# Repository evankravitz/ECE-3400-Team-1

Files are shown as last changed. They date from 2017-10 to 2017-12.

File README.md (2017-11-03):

# [Start Bootstrap - Agency](https://startbootstrap.com/template-overviews/agency/)

[Agency](https://startbootstrap.com/template-overviews/agency/) is a one page agency portfolio theme for [Bootstrap](http://getbootstrap.com/) created by [Start Bootstrap](http://startbootstrap.com/). This theme features several content sections, a responsive portfolio grid with hover effects, full page portfolio item modals, a responsive timeline, and a working PHP contact form.

## Preview

Agency Preview (https://blackrockdigital.github.io/startbootstrap-agency/)

**[View Live Preview](https://blackrockdigital.github.io/startbootstrap-agency/)**

## Status




dependencies Status (https://david-dm.org/BlackrockDigital/startbootstrap-agency)
devDependencies Status (https://david-dm.org/BlackrockDigital/startbootstrap-agency?type=dev)

## Download and Installation

To begin using this template, choose one of the following options to get started:
* [Download the latest release on Start Bootstrap](https://startbootstrap.com/template-overviews/agency/)
* Install via npm: `npm i startbootstrap-agency`
* Clone the repo: `git clone https://github.com/BlackrockDigital/startbootstrap-agency.git`
* [Fork, Clone, or Download on GitHub](https://github.com/BlackrockDigital/startbootstrap-agency)

## Usage

### Basic Usage

After downloading, simply edit the HTML and CSS files included with the template in your favorite text editor to make changes. These are the only files you need to worry about, you can ignore everything else! To preview the changes you make to the code, you can open the `index.html` file in your web browser.

### Advanced Usage

After installation, run `npm install` and then run `gulp dev` which will open up a preview of the template in your default browser, watch for changes to core template files, and live reload the browser when changes are saved. You can view the `gulpfile.js` to see which tasks are included with the dev environment.

#### Gulp Tasks

- `gulp` the default task that builds everything
- `gulp dev` browserSync opens the project in your default browser and live reloads when changes are made
- `gulp sass` compiles SCSS files into CSS
- `gulp minify-css` minifies the compiled CSS file
- `gulp minify-js` minifies the themes JS file
- `gulp copy` copies dependencies from node_modules to the vendor directory

## Bugs and Issues

Have a bug or an issue with this template? [Open a new issue](https://github.com/BlackrockDigital/startbootstrap-agency/issues) here on GitHub or leave a comment on the [template overview page at Start Bootstrap](http://startbootstrap.com/template-overviews/agency/).

## Custom Builds

You can hire Start Bootstrap to create a custom build of any template, or create something from scratch using Bootstrap. For more information, visit the **[custom design services page](https://startbootstrap.com/bootstrap-design-services/)**.

## About

Start Bootstrap is an open source library of free Bootstrap templates and themes. All of the free templates and themes on Start Bootstrap are released under the MIT license, which means you can use them for any purpose, even for commercial projects.

* https://startbootstrap.com
* https://twitter.com/SBootstrap

Start Bootstrap was created by and is maintained by **[David Miller](http://davidmiller.io/)**, Owner of [Blackrock Digital](http://blackrockdigital.io/).

* http://davidmiller.io
* https://twitter.com/davidmillerskt
* https://github.com/davidtmiller

Start Bootstrap is based on the [Bootstrap](http://getbootstrap.com/) framework created by [Mark Otto](https://twitter.com/mdo) and [Jacob Thorton](https://twitter.com/fat).

## Copyright and License

Copyright 2013-2017 Blackrock Digital LLC. Code released under the [MIT](https://github.com/BlackrockDigital/startbootstrap-agency/blob/gh-pages/LICENSE) license.

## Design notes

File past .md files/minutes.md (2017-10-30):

# Minutes

### 9/1 Meeting

11:15 Upson 349

Present: All

Absent: None

Meeting begins with pleasantries and small talk.
Evan discusses adding everyone to Github.
Turns out issue is with Cornell’s github enterprises system.
Evan adds everyone’s personal accounts..
Everyone sends Evan headshots to add to the website.
Begin writing the contract.
Various discussions about elements of the contract, etc (see contract for more details).
Contract signed.
We talk about adding more pages to the website..
Michael will add robot stuff to the lab1 page.
How to submit? Email to kirsten?
MEETING ADJOURNED at 12:06PM

### 9/15 Meeting:
11:15 Kimball B11

Present: All
Absent: Radhika, due to illness.  We hope she feels better soon :( 

We discuss the work we have done on our individual subteams and deliberate on how to tackle the rest of the objectives related to lab 2 and milestone 1. 
Optical team realizes they have not made the modifications necessary to make the Arduino light an LED in response to incident IR light, so we discuss when we can meet to work on that objective.
The robotics team explains that our robot is able to stop at junctions with extreme accuracy, but it is having trouble following a line.  We figure the reason the robot is having this trouble is because the servos that run the two wheels are not operating at the same speed.  The robotics team adds that the robot is having trouble moving forward in a straight line even when it is not attempting to follow a line, which further confirms our hypothesis. 

The meeting is adjourned at 12:06PM

### 9/29 Meeting
11:20 AM, Hollister B11

Present: Evan, TJ, Frannie, Radhika, Katherine, Michael
Absent: None

1. Discussed buying new IR sensor that uses digital pins
	* Pros: 
		* only uses one digital pin, rather than 3-4 analog pins
		* Makes line following easier
	* Cons: 
		* Costs go towards our budget
	* Radhika will email Kirstin to try to buy part
2. Explained Finite State Machine
	* Need a method where the input is a Direction enum, and it will turn and follow a line until the next junction.
3. Chose teams for lab 3
	* Acoustic team: TJ, Michael, Frannie
	* Graphics team: Katherine, Radhika, Evan

MEETING ADJOURNED at 12:05 PM

### 10/20 Meeting
11:20 AM, Hollister B11

Present: Evan, TJ, Frannie, Radhika, Katherine, Michael

Absent: None

1. Lab today
	* Working to combine the VGA and wireless communication teams
	* Need to do integration part, update maze part
	* Idea is to send 2 8-bit arrays
2. Milestone 3 due Monday Nov 6th
	* Need:
		* Working algorithm that explores maze
		* Indication that robot is done
		* In real life and in simulation
	* To do:
		* Line sensing, following and turning - Katherine and Radhika
		* Editing chassis and wall sensors - Michael, Frannie
		* Compiling code for full robot - TJ, Evan
3. Future work
	* PCB stuff - Michael, TJ, Katherine
	* Algorithm - Radhika, Frannie
	* Update website - Katherine, Evan

Motion to Adjourn: TJ

Seconded: Evan

MEETING ADJOURNED at 12:05 PM

### 10/27 Meeting
11:20 AM, Hollister B11

Present: Frannie, Radhika, Katherine, Michael, Evan, TJ

Absent: None :) 

1. Discussed Milestone 3.
	* Done:
		* Simulation of working algorithm that explores maze using DFS in Java -Evan & TJ 
		* Simulation that indicates that robot is done - Evan & TJ
		* Editing chassis - Michael & Frannie 
		* Started work on PCB - Michael & Frannie
		* Continued work on robot using new line sensors - Katherine & Radhika
	* To do:
		* Line sensing, following and turning - Katherine and Radhika
		* Implementing wall sensors - Michael, Frannie
		* Compiling code for full robot - TJ, Evan
		* Transferring the java code for the simulation into Arduino language to implement the real- life 
		aspect of Milestone 3 - Evan, TJ, Frannie 
3. Future work
	* PCB stuff - Michael, TJ, Katherine
	* Algorithm - Radhika, Frannie
	* Update website - Katherine, Evan

Motion to Adjourn: Katherine

Seconded: Frannie 

MEETING ADJOURNED at 12:05 PM

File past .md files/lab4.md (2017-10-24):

[Home](./README.md) 

# Lab 4

## Radio Team
Radhika, Katherine and Evan

### Introduction 
For the radio subteam of this lab, our goal was to communicate information between two arduinos through radio communication using two transceivers. We wanted to send simulated maze data from one arduino, which was set up as the transmitter, to another arduino, which was setup as a reciever. We also wanted to observe the range of the radio communication with different power/speed settings and look how many packets were successfully transmitted. 

### Materials Used 

- 2 Nordic nRF24L01+ transceivers
- 2 Arduino Unos (one was shared with the other sub-team)
- 2 USB A/B cables
- 2 radio breakout boards with headers

### Getting Started with the RF24 Transceivers
As directed in the lab, first, we downloaded the RF24 arduino library. Then, to begin with simple tests of the transceivers, we used the 'Getting Started' code that was provided to us in the lab as opposed to the example code that came with the arduino library. Before we could begin, we had to adjust the identifier numbers for our two pipes using the formula 2(3D + N) + X where D is the day of our lab, N is our team number, and X was 0 and 1 for each of our 2 radios. Our calculated values happened to be 2 and 3,  the same as the ones in the sample code, as shown below:

```
// Radio pipe addresses for the 2 nodes to communicate.
const uint64_t pipes[2] = { 0x0000000002LL, 0x0000000003LL };
```
We first tested the sample code that was provided to us. We set up one arduino to be the transmitter by typing 'T' into the serial monitor of that arduino. The other arduino automatically became a reciever. The sample code was written to sent the time at which the data was being sent to the reciever. If the data was successfully sent, the transmitter then waits on a confirmation from the reciever. If the data wasn't sent successfully, the code tries to send the data again in 1 second. The code has a 200ms timeout value, so if the receiver hasn't confirmed that it has recieved the data in 200 ms, the code prints out a corresponding statement. If the receiver does confirm before timeout, the calculated round-trip delay time is printed out.  This is reflected in the following code:

```
    unsigned long time = millis();
    printf("Now sending %lu...",time);
    bool ok = radio.write( &time, sizeof(unsigned long) );

    if (ok)
       printf("ok...");	
    else
       printf("failed.\n\r");

    radio.startListening();

// Wait here until we get a response, or timeout (200ms)
    unsigned long started_waiting_at = millis();
    bool timeout = false;
    while ( ! radio.available() && ! timeout )
      if (millis() - started_waiting_at > 200 )
        timeout = true;

    // Describe the results
    if ( timeout )
    {
      printf("Failed, response timed out.\n\r");
    }
    else
    {
      // Grab the response, compare, and send to debugging spew
      unsigned long got_time;
      radio.read( &got_time, sizeof(unsigned long) );

      // Spew it
      printf("Got response %lu, round-trip delay: %lu\n\r",got_time,millis()-got_time);
    }

    // Try again 1s later
    delay(1000);
  }
```
We tried different ranges for sending and receiving data. We didn't see a major drop in successful transmissions until we were almost in 2 separate rooms, so we believe the range of the radio communication is more than enough for our applications.

In the next steps, we modified the data we were sending between arduinos to reflect simulated maze data.

### Sending full maze coordinates and maze updates with wireless communication
To send the full maze coordinates, we altered the code to send a 5x5 array of unsigned chars. When sending and receiving transmissions, the arduino needs to be told what size packet it will be sending or receiving, so the key is to explicitly state what the maze size was when reading and writing data. 

##### So for sending and receiving a 5x5 array: 

```
unsigned char maze[5][5];
// different maze values were randomly assigned and sent 

//sending 
bool ok = radio.write( &maze, sizeof(unsigned char)*25);
//receiving 
bool done = radio.read( &maze, sizeof(unsigned char)*25);
```

We noticed that when we increased the packet size, more packets of information were being dropped or taking too long to transmit, so we also played around with higher data rates and power levels. This yielded less dropped packets of information that transmitted faster, but we tried to err on the side of less power consumption. 

```
// set the power
// RF24_PA_MIN=-18dBm, RF24_PA_LOW=-12dBm, RF24_PA_MED=-6dBM, and RF24_PA_HIGH=0dBm.
radio.setPALevel(RF24_PA_MED);
//RF24_250KBPS for 250kbs, RF24_1MBPS for 1Mbps, or RF24_2MBPS for 2Mbps
radio.setDataRate(RF24_2MBPS);
```

Here is a video of one arduino sending the entire maze to another: 

<video width="460" height="270" controls preload> 
    <source src="resources/maze.mp4"></source> 
</video>

##### For sending and receiving maze updates via individual coordinate points: 
When sending maze updates, one arduino sent a 1x3 array of unsigned chars--the first two chars being the maze coordinates, and the third being new information that corresponded with that data point. The second arduino had a 5x5 maze array initialized on it so that the correct coordinate could be updated to reflect the incoming information as it was received. 

```
//random coordinate and data values were assigned
unsigned char updates[3]; 
updates[0] = x;
updates[1] = y;
updates[2] = data;

//sending individual maze updates
bool ok = radio.write( &updates, sizeof(unsigned char)*3);

//receiving and updating internal memory of maze 
done = radio.read( &updates, sizeof(unsigned char)*3 );
maze[updates[0]][updates[1]]=updates[2];
```

Here is a video of the maze updates being sent from one Arduino to another: 

<video width="460" height="270" controls preload> 
    <source src="resources/updates.mp4"></source> 
</video>

### Sending information from base station to FPGA 

For the final part of the lab, we had to create a system for sending maze information from the Arduino base station to the FPGA. Since the robot was not yet operational, and we had already demonstrated that we can communicate wirelessly between the Arduinos, we generated test robot coordinate data to simulate the robot traversing the maze. Since we were able to demonstrate communication between the Arduinos, and from the Arduino to the base station, it will be relatively straightforward to link all of these devices together. Note that we did not demonstrate the communication of treasure and wall data from the Arduino to the FPGA. We have established a preliminary protocol for transmitting this data, but have not yet demonstrated this in practice. 

Here is the Arduino code we wrote for this component of the lab (each part will be explained)

```
int delayTime = 500; //ms;
int setupTime = 50; //ms;
String inputSignals[32] = {
                        "00000", "01000", "10000", "11000",
                        "00001", "01001","10001", "11001",
                        "00010",  "01010", "10010", "11010",
                        "00011", "01011", "10011", "11011",
                        "00100", "01100", "10100", "11100",
                        "00101", "01101","10101", "11101", 
                        "00110", "01110", "10110", "11110",
                        "00111", "01111", "10111", "11111",
                        };

void generateClock(){
  
}

void setup() {
  Serial.begin(9600);
  pinMode(7,OUTPUT);
  pinMode(6,OUTPUT);
  pinMode(5,OUTPUT);
  pinMode(4,OUTPUT);
  pinMode(3,OUTPUT);
  pinMode(2,OUTPUT);

}

void loop() {
  
  for (int i = 0; i<32; i++){
    String signalWord = inputSignals[i];
    sendWord(signalWord);
    delay(delayTime);   
  }
}

void sendWord(String signalWord){
  digitalWrite(2, LOW);
  delay(setupTime);
  writeWord(signalWord);
  delay(setupTime);
  digitalWrite(2, HIGH);
}

void writeWord(String signalWord){
  for (int i = 0; i<5; i++){
    if (signalWord.charAt(i) == '0'){
      digitalWrite(7-i, LOW);
    }
    else{
      digitalWrite(7-i, HIGH);
    }
  }
}
```

As discussed, the maze coordinate are encoded in a 5 bit word. In the Arduino code, we hard coded all 20 maze coordinates that the robot could possibly reach. This can be seen when we instantiate the `inputSignals` array. 

Since the FPGA reads this word on the rising edge of a clock, we had to create a 1-bit psuedo-clock signal in Arduino that is sychronized to change when we are ready to read the data. This is done in the `sendWord` method. Pin 2 corresponds to our "clock". We write a `LOW` value to the clock pin, and then wait `setupTime` amount of milliseconds before proceeding to actually write the coordinates to pins 7-3. We wait `setupTime` milliseconds before flipping the clock to a `HIGH` signal. Our thinking was that there is some propagation delay in the circuit. 50 milliseconds is plenty of time for the signal to set up, and for the FPGA to sample the correct value. If we didn't clock our signal, then we would run into issues sampling the signal when it is transitioning between values. 

The `writeWord` method is relatively straightforwards. It simply iterates through the word string, and then writes the values to the appropriate pin. 

The output pins corresponding to the coordinate data and clock (digital pins 7-2) were connected to a voltage divider array in order to be sent to the FPGA (to be discussed in next section).

## FPGA Team
TJ, Frannie, Michael

### Introduction

For our sub-team, the goal of this lab was to recieve packets of information from the Arduino, and then use this information to update the VGA monitor using the FPGA. In order to accomplish this, we first built off of our team's work from Lab 3.

#### Materials used:

- FPGA DE0-Nano
- VGA-FPGA adapter
- VGA cable and monitor

### Drawing a 4x5 grid

Changing our grid size was a fairly simple process, but did require some troubleshooting. First we updated the line `reg[7:0] grid1[2:0] [2:0]` to `reg[7:0] grid1[3:0] [4:0]` in our main module. We then assigned a color to each register in grid1 to create a checkerboard pattern. 

When we uploaded the code to the FPGA, the squares were too large to view the full grid.  Thus, we changed the always block in our `GridSelector` module to the following:

```
always @ (*) begin
	GRID_X = PIXEL_COORD_X / 96;
	GRID_Y = PIXEL_COORD_Y / 96;
end
```

Instead of bitshifting by 7 bits (dividing by 128 as before), we decided to divide by 96, since the height of the monitor is 480 pixels. 480 pixels / 5 squares = 96 pixels / square.

The squares were now all visible, but the grid would only display 4x4. After reviewing our code for a while, we realized we hadn't updated the registers `GRID_X` and `GRID_Y` to hold enough bits. We changed both of these to 4 bit registers and the grid was now 4x5!

### Changing color based on location

Next, we needed to be able to update the grid to show the current location of the robot, as well as visited locations. To do this, we needed to rework the code from last lab, which had 4 different maps stored in memory. Rather than have each possible map stored in memory, we decided to update the map dynamically.

To accomplish this, we created the following state machine:

```
reg[7:0] grid1[3:0][4:0];
reg[7:0] currentGrid;
   
//state machine 
always @(posedge CLOCK_25) begin
  if (GRID_X > 3) begin //colors squares that aren't in the 4x5 grid black (unreachable)
    PIXEL_COLOR <= black;
  end
  else begin
  currentGrid <= grid1[GRID_X][GRID_Y];
    if (currentGrid == 0) begin //if no input, color current square white (unvisited)
      PIXEL_COLOR <= white;
    end
    if (currentGrid[0] == 1) begin //if LSB is 1, color current square pink (visited)
      PIXEL_COLOR <= pink;
    end
  end
end
```

We then created a quick test to determine whether our implementation could receive inputs over time, update the grid and remember previous locations.

We created two registers to encode x and y locations, and used the one second timer to update x and y. Then the square in the grid at location (x,y) was assigned `8'b1` which corresponded to a visited square in our FSM.

```
reg[2:0] x;
reg[2:0] y;

if (led_counter == ONE_SEC) begin 
	led_state   <= ~led_state;
	led_counter <= 25'b0;
	if (y==3'b100) begin // you're at the bottom of the grid
		y<= 3'b0;
		x<=x+3'b001;
	end
	else begin
		y <= y + 3'b1;
	end 
	grid1[x][y] <= 8'b1;
end

```
 Here is a video of this incrementation: 

<video width="460" height="270" controls preload> 
    <source src="resources/first.mp4"></source> 
</video>

### FPGA Communication with Arduino

With our 'state machine' working properly, it was easy to quickly assign different states to a grid tile and have a record of visited tiles. Our last step was to get the two halves of our assignment working together. We coordinated with the Arduino half of the team to make a protocol for robot position. In this case, we used the simplest possible communication scheme: A 5 bit array, with the first 2 bits representing x position, and the latter 3 representing y position. 

Our FPGA was hooked up directly to the Arduino by a set of 6 wires (5 data bits, one valid bit). This setup took a frustrating amount of time, because the DE0 Nano datasheet's pinout diagram for GPIO-1 is unintuitive (to put it lightly). Once our pins were indeed hooked up correctly (this took a lot of oscilloscope debugging on our part), we worked on properly interpreting messages from the Arduino.

We used an independent module for the reading of data from the Arduino, called inputReader:

 ```
 module inputReader(
valid,
arduinoInput,
robotX,
robotY,
preX,
preY);

input valid;
input [4:0] arduinoInput;
output reg [1:0] robotX;
output reg [2:0] robotY;

output reg [1:0] preX;
output reg [2:0] preY;

always @ (posedge valid) begin
	preX = robotX;
	preY = robotY;
	robotX = arduinoInput[4:3];
	robotY = arduinoInput[2:0];
end

endmodule
```
 
We initially struggled to get data to correctly update (our screen update schema was simple - put the robot on the tile the Arduino sent, record all past tiles sent as visited, and make the rest unvisited). We observed that in general, the tiles were flipping to visited in the order we expected, but not at a constant rate. Certain tiles would change colors two at a time. This signaled to us that the FPGA was not reading the data correctly. Because our inputReader module was reading data whenever the valid bit was high, the FPGA was capturing incorrect grid values that occurred when the output bits from the Arduino were flipping. We altered both the Arduino and the FPGA code, to capture Arduino data only on the pos edge of the valid bit, thereby preventing our error.

We were able to successfully communicate information wirelessly from one Arduino to another, then display it on a screen using the FPGA. See the below video:

<video width="460" height="270" controls preload> 
    <source src="resources/second.mp4"></source> 
</video>

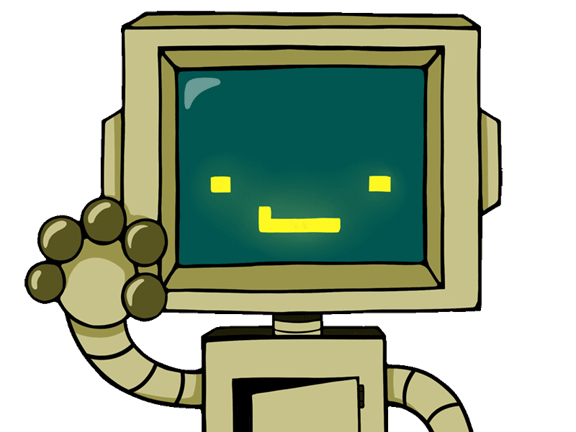
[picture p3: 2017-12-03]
img/portfolio/final.gif

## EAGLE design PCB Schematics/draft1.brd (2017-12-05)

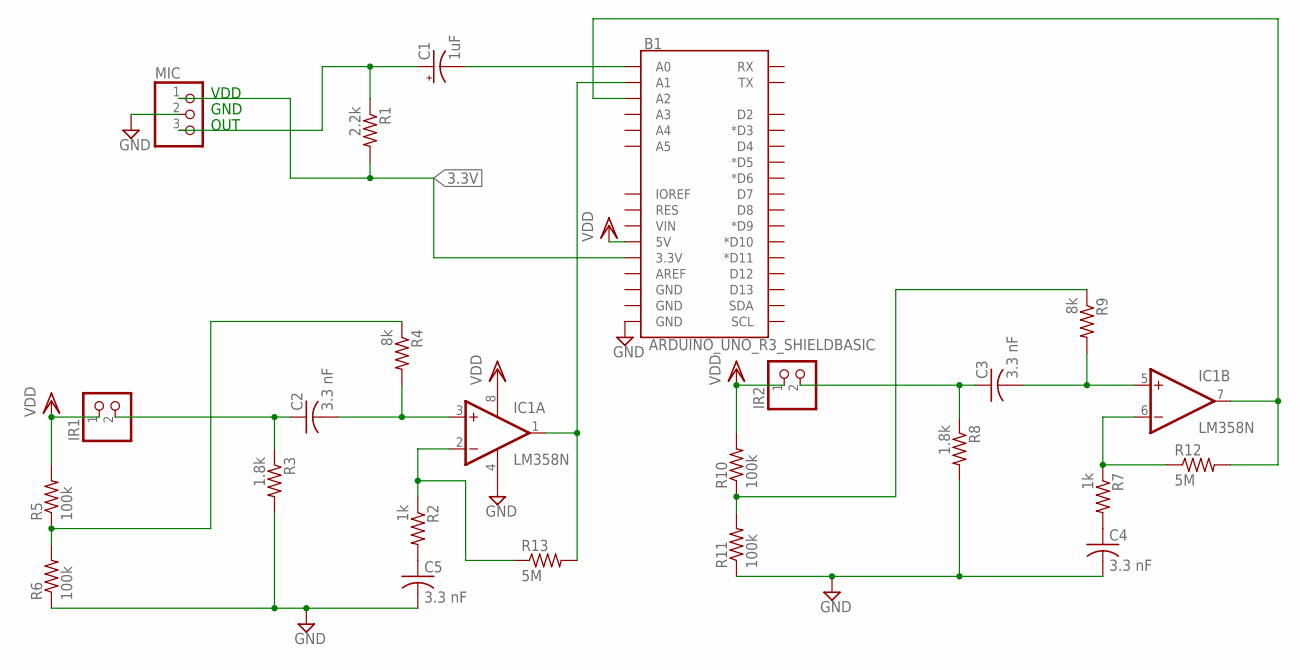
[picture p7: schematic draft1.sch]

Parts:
B1: ARDUINO_UNO_R3_SHIELDBASIC; UNO_R3_SHIELD
C1: 1uF; E5-6
C2, C3, C4, C5: 3.3 nF; C025-040X050
IC1: LM358N; DIL08
IR1, IR2: PINHD-1X2; 1X02
MIC: PINHD-1X3; 1X03
R1: 2.2k; 0207/7
R2, R7: 1k; 0207/7
R3, R8: 1.8k; 0207/7
R4, R9: 8k; 0207/7
R5, R6, R10, R11: 100k; 0207/7
R12, R13: 5M; 0207/7

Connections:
3.3V: B1.3.3V, MIC.1, R1.2
GND: B1.GND@0 (GND), C4.2, C5.2, IC1.4 (V-), MIC.2, R3.2, R6.1, R8.2, R11.1
unnamed: B1.A0, C1.-
unnamed: C1.+, MIC.3, R1.1
unnamed: B1.A2, IC1.7 (OUT), R12.2
unnamed: C4.1, R7.2
unnamed: C3.1, IR2.2, R8.1
unnamed: B1.A1, IC1.1 (OUT), R13.2
unnamed: C2.2, IC1.3 (+IN), R4.2
unnamed: IC1.6 (-IN), R7.1, R12.1
unnamed: C3.2, IC1.5 (+IN), R9.2
unnamed: IC1.2 (-IN), R2.1, R13.1
unnamed: R9.1, R10.1, R11.2
unnamed: R4.1, R5.1, R6.2
unnamed: C5.1, R2.2
unnamed: C2.1, IR1.2, R3.1
VDD: B1.5V, IC1.8 (V+), IR1.1, IR2.1, R5.2, R10.2

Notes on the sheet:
VDD
GND
OUT

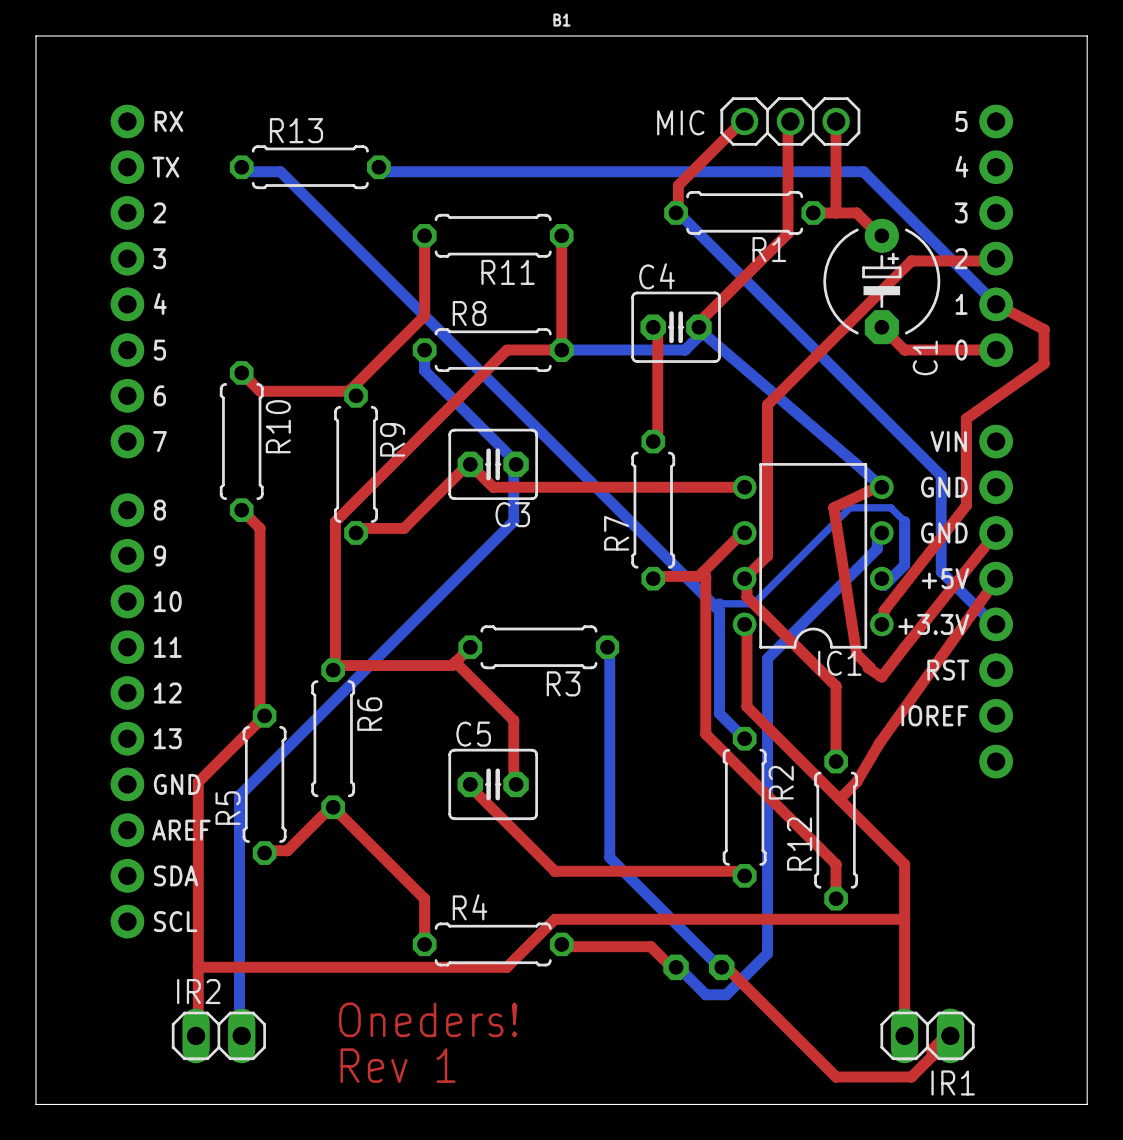
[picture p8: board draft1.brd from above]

Board: 2 copper layers, 58.4 x 59.4 mm, 23 parts (1 on the bottom side), 17 nets.

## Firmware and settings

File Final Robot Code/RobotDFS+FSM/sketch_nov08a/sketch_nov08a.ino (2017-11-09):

#include <StackArray.h>


//Definitions
//for Fourier Transform
#define LOG_OUT 1 // use the log output function
#define FFT_N 256 // set to 256 point fft

//Libraries
//#include <FFT.h> // include the FFT library
#include <QTRSensors.h> //QTR sensor (line sensor) library
#include <Servo.h> // servo library


//detectStart
//int micPin = A0; //microphone connected to analog 0, code currently does this in setup in ADMUX

//detectTreasure
//int treasurePin = A0; // treasure connected to analog 0, code does this in setup in ADMUX
long clockFreq = 16E6;
int divisionFactor = 32;
int conversionTime = 13;
int numSamples = 256;
float samplingFrequency = ((clockFreq/((float)divisionFactor))/conversionTime);
float binWidth = samplingFrequency/numSamples;

//detectWalls
int wallPinLeft = A5;
int wallPinMid = A4;
int wallPinRight = A3;

//int distanceLeft = 0;
//int distanceMid = 0;
//int distanceRight = 0;

boolean wallLeft = false;
boolean wallRight = false;
boolean wallMid = false;

char maze[9][11];


//Line Following
Servo servoL;
Servo servoR;

// Change the values below to suit your robot's motors, weight, wheel type, etc.
#define KP 0.1
#define KD 0.3
#define Lspeed 180
#define Rspeed 85
#define ML_MAX_SPEED 180
#define MR_MAX_SPEED 0
#define MIDDLE_SENSOR 2
#define NUM_SENSORS  3     // number of sensors used
#define TIMEOUT       2500  // waits for 2500 us for sensor outputs to go low
#define EMITTER_PIN    QTR_NO_EMITTER_PIN  // emitter is controlled by digital pin 2
#define DEBUG 0 // set to 1 if serial debug output needed

int leftMotorSpeed = Lspeed;
int rightMotorSpeed = Rspeed;
static int LTurnL = 56; 
static int LTurnR = 56; 
static int RTurnL = 180; 
static int RTurnR = 170;

int lastError = 0;
int position =0;
int error =0;
unsigned int sensors[3];
boolean isJunction;
boolean sameJunct = false;
int junkSensor =0;

//IMPROVEMENTS? range of no correction 900-1100? different KP and KD for neg/pos error? percent correction tracking? 

QTRSensorsRC qtrrc((unsigned char[]) {2,3,4} ,NUM_SENSORS, TIMEOUT, EMITTER_PIN);

unsigned int sensorValues[NUM_SENSORS];
//uint8_t maze[9][11];

///// Everything above is from the FSM code ^^^^

#include <StackArray.h>
#define Unexplored 0
#define Explored 1
#define Wall 2

#define North 0
#define East 1
#define South 2
#define West 3

#define Left 3 
#define Right 1
#define Straight 0
#define Backwards 2



void setup(){
    Serial.begin(9600); // use the serial port
    pinMode(5, OUTPUT);
    pinMode(6, OUTPUT);  
    pinMode(A0, INPUT); //junction sensor
     //distance pins
  pinMode(A5, INPUT);
  pinMode(A3, INPUT);
  pinMode(A4, INPUT);

  servoL.attach(5);
  servoR.attach(6);

  set_motors(90,90);
  
  pinMode(13, OUTPUT);
  digitalWrite(13, HIGH);    // turn on Arduino's LED to indicate we are in calibration mode
  for (int i = 0; i < 100; i++)  // make the calibration take about 10 seconds
  {
    //Serial.println("Calibrating");
    qtrrc.calibrate();       // reads all sensors 10 times at 2500 us per read (i.e. ~25 ms per call)
  }
  digitalWrite(13, LOW);     // turn off Arduino's LED to indicate we are through with calibration
 
}


char currentOrientation; //We'll create some way of computing the current orientation later

char maze [9] [11];
char currPos[2]; 
char frontier[20]; 
StackArray <char> visitedStack;
char reachableCells[4];
char wallsRelativeDirs[2];
char possibleWallPosition[2];
char prevPos[2];
char moveToPerform;


void resetMaze() {
  // Resets the arduino's underlying maze to be completely unexplored
  for (int i=0; i<11; i++){
    for (int j= 0; j<9; j++){
      maze[j][i]= Unexplored; 
      
    }
  }
 }




 void loop(){
  prevPos[0] = currPos[0];
  prevPos[1] = currPos[1];
  resetMaze();
  initializeCurrPos();
  addToFrontier(convertCoordsToChar(currPos));
  visitedStack.push(convertCoordsToChar(currPos));
  while (!frontierIsEmpty()){
    maze[currPos[0]][currPos[1]] = Explored;
    removeFromFrontier(convertCoordsToChar(currPos));
    addWallsToMaze();
    getReachableCells();
    addUnvisitedSurroundingNodesToFrontier();
    updateCurrPosAndVisitedSet();
    if (!frontierIsEmpty()){
      addWallsToMaze();
      getReachableCells();
      addUnvisitedSurroundingNodesToFrontier();
    }
   updateMove();
   performMove();
  
  }
  doneWithNavigation();
  
  
 }

 void performMove(){
  
 }

void doneWithNavigation(){
  
}

void updateMove(){
  int dx = currPos[0] - prevPos[0];
  int dy = currPos[1] - prevPos[1];
  if ((dx == 2 && currentOrientation==East) //displace east, facing east
     || (dy == -2 && currentOrientation==North) //displace north, facing north
     || (dx == -2 && currentOrientation==West) //displace west, facing west
     || (dy == 2 && currentOrientation==South)){      //displace south, facing south
        moveToPerform = Straight;
  }
  else if ((dy == 2  && currentOrientation==East) //displace south, facing east
     || (dx == -2 && currentOrientation==South) //displace west, facing south
     || (dy == -2 && currentOrientation==West) //displace north, facing west
     || (dx == 2 && currentOrientation==North)) //displace east, facing north
     {
        moveToPerform = Right;
  }
    else if ((dy == 2  && currentOrientation==North) //displace south, facing north
     || (dx == -2 && currentOrientation==East) //displace west, facing east
     || (dy == -2 && currentOrientation==South) //displace north, facing south
     || (dx == 2 && currentOrientation==West)) //displace east, facing west
     {
        moveToPerform = Backwards;
  }
  else{
    moveToPerform == Left;
  }

  

  

  
}


char generateNewDirection(char currOrientation, char displacementOrientation){
  //go north
  if ((currOrientation==North && displacementOrientation==Straight) || //facing north, looking in front 
  (currOrientation==East && displacementOrientation==Left) || //facing east, looking left
  (currOrientation==South && displacementOrientation==Backwards) || // facing south, looking behind
  (currOrientation==West && displacementOrientation==Right)){ // facing west, looking right
    return North;
  }
  //go east
  if ((currOrientation==North && displacementOrientation==Right) || //facing north, looking right
  (currOrientation==East && displacementOrientation==Straight) || //facing east, looking in front
  (currOrientation==South && displacementOrientation==Left) || // facing south, looking left
  (currOrientation==West && displacementOrientation==Backwards)){ //facing west, looking behind
    return East;
  }
  //go south
  if ((currOrientation==North && displacementOrientation==Backwards) || //facing north, looking behind
  (currOrientation==East && displacementOrientation==Right) || //facing east, looking right
  (currOrientation==South && displacementOrientation==Straight) || // facing south, looking in front
  (currOrientation==West && displacementOrientation==Left)){ // facing west, looking left
    return South;
  }
  //go west
  if ((currOrientation==North && displacementOrientation==Left) || //facing north, looking left
  (currOrientation==East && displacementOrientation==Backwards) || //facing east, looking behind
  (currOrientation==South && displacementOrientation==Right) || // facing south, looking right
  (currOrientation==West && displacementOrientation==Straight)){ // facing west, looking in fornt
    return West;
  } 
  
}
void getReachableCells(){
  getAdjacentWall(0); //in front
  if (maze[possibleWallPosition[0]][possibleWallPosition[1]] != Wall){
    char reachableCellArray[2]; 
    reachableCellArray[0] = currPos[0] + 2*(possibleWallPosition[0] - currPos[0]);
    reachableCellArray[1] = currPos[0] + 2*(possibleWallPosition[1] - currPos[1]);
    reachableCells[0] = convertCoordsToChar(reachableCellArray);
  }
  getAdjacentWall(1); //right
  if (maze[possibleWallPosition[0]][possibleWallPosition[1]] != Wall){
    char reachableCellArray[2]; 
    reachableCellArray[0] = currPos[0] + 2*(possibleWallPosition[0] - currPos[0]);
    reachableCellArray[1] = currPos[0] + 2*(possibleWallPosition[1] - currPos[1]);
    reachableCells[1] = convertCoordsToChar(reachableCellArray);
  }
  getAdjacentWall(2); //left
  if (maze[possibleWallPosition[0]][possibleWallPosition[1]] != Wall){
    char reachableCellArray[2]; 
    reachableCellArray[0] = currPos[0] + 2*(possibleWallPosition[0] - currPos[0]);
    reachableCellArray[1] = currPos[0] + 2*(possibleWallPosition[1] - currPos[1]);
    reachableCells[2] = convertCoordsToChar(reachableCellArray);
  }
  reachableCells[3] = convertCoordsToChar(prevPos);
  
  
}
void getAdjacentWall(char dir){
  possibleWallPosition[0] = currPos[0];
  possibleWallPosition[1] = currPos[1];
  char directionToGo = generateNewDirection(currentOrientation, dir);
  //go straight
  if (directionToGo == North){ 
    possibleWallPosition[1] = currPos[1] -1;
  }
  //go right
  if (directionToGo == East){
    possibleWallPosition[0] = currPos[0] + 1;
  }
  //go backwards
  if (directionToGo == South ){ 
    possibleWallPosition[1] = currPos[1]+1;
  }
  //go left
  if (directionToGo == West){ 
    possibleWallPosition[0] = currPos[0]-1;
  } 
}
 



void updateCurrPosAndVisitedSet(){
  boolean foundUnexplored = false;
  char newCurrPos[2];
  for (int i = 0; i<4; i++){
    if (reachableCells[i]!=0){
      //conversion between int coordinates to array coordinates
      int ypos = 2*((reachableCells[i]-1)/4)+1;
      int xpos = 2*((reachableCells[i]-1)%4)+1;
      if (maze[xpos][ypos] == Explored){
        foundUnexplored = true;
        newCurrPos[0] = xpos; newCurrPos[1] = ypos;
        break;
      }
    }
  }
  if (!foundUnexplored){
    char lastVisited = visitedStack.pop();
    int newYpos = 2*((reachableCells[i]-1)/4)+1;
    int newXpos = 2*((reachableCells[i]-1)%4)+1;
    newCurrPos[0] = newXpos;
    newCurrPos[1] = newYpos;
  }
  else{
    visitedStack.push(convertCoordsToChar(currPos));
  }
  prevPos[0] = currPos[0];
  prevPos[1] = currPos[1];
  currPos[0] = newCurrPos[0];
  currPos[1] = newCurrPos[1];
}

void getWalls(){
  
}
void addWallsToMaze(){
  getWalls(); //this method will be defined somewhere. 
  char wallCoord[2];
  for (int i = 0; i<3; i++){
  
    if (wallsRelativeDirs[i] == 0){  // there's a wall ther
      if (i ==0){
        getAdjacentWall(3);
      }
      if (i==1){
        getAdjacentWall(0);
      }
      else{
        getAdjacentWall(1);
      }
    }
    maze[possibleWallPosition[0]][possibleWallPosition[1]] = Wall;
  }
  
}

void addUnvisitedSurroundingNodesToFrontier(){
  for (int i = 0; i<4; i++){
    if (reachableCells[i]!=0){
       int ypos = 2*((reachableCells[i]-1)/4)+1;
       int xpos = 2*((reachableCells[i]-1)%4)+1;
       if (maze[xpos][ypos] == Unexplored){
          addToFrontier(reachableCells[i]);
       }
   }
  }
}
 void initializeCurrPos(){
  currPos[0]= 7;
  currPos[1]= 9;
 }



 char convertCoordsToChar(char coodinateArray[]){
  if (coodinateArray[0]==1 && coodinateArray[1]==1){
    return (char) 1; 
  }
  if (coodinateArray[0]==3 && coodinateArray[1]==1 ){
    return (char) 2; 
  }
  if (coodinateArray[0]==5 && coodinateArray[1]==1 ){
    return (char) 3; 
  }
  if (coodinateArray[0]==7 && coodinateArray[1]==1 ){
    return (char) 4; 
  }
  if (coodinateArray[0]==1 && coodinateArray[1]==3 ){
    return (char) 5; 
  }
  if (coodinateArray[0]==3 && coodinateArray[1]==3 ){
    return (char) 6; 
  }
  if (coodinateArray[0]==5 && coodinateArray[1]==3 ){
    return (char) 7; 
  }
  if (coodinateArray[0]==7 && coodinateArray[1]==3 ){
    return (char) 8; 
  }
  if (coodinateArray[0]==1 && coodinateArray[1]==5 ){
    return (char) 9; 
  }
  if (coodinateArray[0]==3 && coodinateArray[1]==5 ){
    return (char) 10; 
  }
  if (coodinateArray[0]==5 && coodinateArray[1]==5 ){
    return (char) 11; 
  }
  if (coodinateArray[0]==7 && coodinateArray[1]==5 ){
    return (char) 12; 
  }
  if (coodinateArray[0]==1 && coodinateArray[1]==7 ){
    return (char) 13; 
  }
  if (coodinateArray[0]==3 && coodinateArray[1]==7 ){
    return (char) 14; 
  }
  if (coodinateArray[0]==5 && coodinateArray[1]==7 ){
    return (char) 15; 
  }
  if (coodinateArray[0]==7 && coodinateArray[1]==7 ){
    return (char) 16; 
  }
  if (coodinateArray[0]==1 && coodinateArray[1]==9 ){
    return (char) 17; 
  }
  if (coodinateArray[0]==3 && coodinateArray[1]==9 ){
    return (char) 18; 
  }
  if (coodinateArray[0]==5 && coodinateArray[1]==9 ){
    return (char) 19; 
  }
  if (coodinateArray[0]==7 && coodinateArray[1]==9 ){
    return (char) 20; 
  }
 }

 boolean containsFrontier(char coordinate){
  if (frontier[coordinate-1] ==1){
    return true;
  }
  return false;
 }

 void addToFrontier(char coordinate){
  if (!containsFrontier(coordinate)){
    frontier[coordinate-1] = 1;
  }
 }

 void removeFromFrontier(char coordinate){
  frontier[coordinate-1] = 0;
 }

boolean frontierIsEmpty(){
  for (int i = 0; i<20; i++){
    if (frontier[i] == 1){
      return false;
    }
  }
  return true;
}
  

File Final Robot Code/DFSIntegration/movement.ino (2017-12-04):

void stop(){
  set_motors(90,90);
  delay(50);
}

void goStraight(){
    //Serial.println(position);
    int motorSpeed = KP * error + KD * (error - lastError);
    lastError = error;
//    if (error > 900 && error < 1100) {
//      motorSpeed = 0; 
//    }
    leftMotorSpeed = Lspeed + motorSpeed*1.2;
    rightMotorSpeed = Rspeed + motorSpeed;

    //Serial.println(leftMotorSpeed);
    //Serial.println(rightMotorSpeed);
    set_motors(leftMotorSpeed, rightMotorSpeed);
  
}

void junction(){
    if(junkSensor==HIGH && !sameJunct){
      isJunction = true;
      sameJunct=true;
    }
   else {
    isJunction = false;
   }
}

void turnLeft(){
  
  leftMotorSpeed = LTurnLw;  //delay(200);
  rightMotorSpeed = LTurnRw;    

  set_motors(leftMotorSpeed, rightMotorSpeed);
 // Serial.println("set motors");
 
  position = qtrrc.readLine(sensors);
 // Serial.println("2");
  while(!(digitalRead(7)==LOW)){
     position = qtrrc.readLine(sensors); 
  }
  //Serial.println("3");
  while(digitalRead(7)==LOW && sensors[1] < 900){
    position = qtrrc.readLine(sensors); 
  }
 // Serial.println("4");
  set_motors(90,90);
  delay(25);
  if(digitalRead(7)==LOW){
    while(digitalRead(7)==LOW) goStraight();
  }
  
  return;

}

void turnRight(){

  leftMotorSpeed = RTurnLw;  //delay(200);
  rightMotorSpeed = RTurnRw;  
  isJunction = true;   

  set_motors(leftMotorSpeed, rightMotorSpeed);
 
  position = qtrrc.readLine(sensors);
  while(!(digitalRead(7)==LOW)){
     position = qtrrc.readLine(sensors); 
  }
  while(digitalRead(7)==LOW | sensors[1]<900){
    position = qtrrc.readLine(sensors); 
  }

  return;

}
 


void set_motors(int motor1speed, int motor2speed) {
  if (motor1speed > ML_MAX_SPEED ) motor1speed = ML_MAX_SPEED; // limit top speed
  if (motor2speed < MR_MAX_SPEED ) motor2speed = MR_MAX_SPEED; // limit top speed
  servoL.write(motor1speed);     // set motor speed
  servoR.write(motor2speed);     // set motor speed
}


void performMove(){
  currentOrientation = generateNewDirection(currentOrientation, moveToPerform);
  if (moveToPerform == Left){
    //Serial.println("Moving Left!");
    moveLeft();
  }
  if (moveToPerform == Right){
   // Serial.println("Moving Right!");

    moveRight();
  }
  if (moveToPerform == Straight){
   // Serial.println("Moving Straight!");

    moveStraight();
  }
  if (moveToPerform == Backwards){
  // Serial.println("Moving Backwards!");

    moveBackwards();
  }
  if (moveToPerform == Stop){
      stop();
  }
 }

void moveLeft(){
 turnLeft();
 stop();
 recordAndTrasmitDataAtTurningJunction();
 moveStraight();
}

void moveRight(){
  turnRight();
  stop();
  recordAndTrasmitDataAtTurningJunction();
  moveStraight();
}

void moveBackwards(){
  turnLeft();
  stop();
  recordAndTrasmitDataAtTurningJunction();
  turnLeft();
  stop();
  moveStraight();
}

void moveStraight(){
//  if analogRead(A0
  while(digitalRead(7)==HIGH){ 
      goStraight();
   }

  sameJunct = false;
  digitalWrite(13, LOW);
  isJunction = false;
  
  while (!isJunction) {
    position = qtrrc.readLine(sensors);
    junkSensor = digitalRead(7);
    
    error = position - 1000;
    junction();
    if (isJunction) {
      stop();
      digitalWrite(13, HIGH);
      
    }
    else  {
      goStraight();
    }
  }
}

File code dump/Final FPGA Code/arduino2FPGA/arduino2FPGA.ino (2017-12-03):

int delayTime = 600; //ms;
boolean coordinate;
boolean top;
boolean right = true;
boolean bottom;
boolean left;
int tres = 0 ;
int x = 0;
int y = 0;
int yPrev = 0;
word data;
String dataString;

#include <SPI.h>
#include "nRF24L01.h"
#include "RF24.h"


//
// Hardware configuration
//

// Set up nRF24L01 radio on SPI bus plus pins 9 & 10

RF24 radio(9, 10);
unsigned char maze[5][5];


//
// Topology
//

// Radio pipe addresses for the 2 nodes to communicate.
const uint64_t pipes[2] = { 0x0000000002LL, 0x0000000003LL };

//
// Role management
//
// Set up role.  This sketch uses the same software for all the nodes
// in this system.  Doing so greatly simplifies testing.
//

// The various roles supported by this sketch
typedef enum { role_ping_out = 1, role_pong_back } role_e;

// The debug-friendly names of those roles
const char* role_friendly_name[] = { "invalid", "Ping out", "Pong back"};

// The role of the current running sketch
role_e role = role_pong_back;


void setup() {
  Serial.begin(9600);
  dataString = "0000000000000000";
  pinMode(A5, OUTPUT); //most sig: if 1, coord, if 0, wall&tres
  pinMode(A4, OUTPUT); // top wall or x-coor
  pinMode(7, OUTPUT); // left wall or x-coor
  pinMode(6, OUTPUT); // bottom wall or y-coor
  pinMode(5, OUTPUT); // right wall or y-coor
  pinMode(4, OUTPUT); //tres or y-coor
  pinMode(3, OUTPUT); //tres or done
  pinMode(2, OUTPUT); //least sig valid


  coordinate = false;




  // Setup and configure rf radio
  //

  radio.begin();

  // optionally, increase the delay between retries & # of retries
  radio.setRetries(15, 15);
  radio.setAutoAck(true);
  // set the channel
  radio.setChannel(0x50);
  // set the power
  // RF24_PA_MIN=-18dBm, RF24_PA_LOW=-12dBm, RF24_PA_MED=-6dBM, and RF24_PA_HIGH=0dBm.
  radio.setPALevel(RF24_PA_MIN);
  //RF24_250KBPS for 250kbs, RF24_1MBPS for 1Mbps, or RF24_2MBPS for 2Mbps
  radio.setDataRate(RF24_1MBPS);


  radio.openWritingPipe(pipes[1]);
  radio.openReadingPipe(1, pipes[0]);

  radio.startListening();

  //
  // Dump the configuration of the rf unit for debugging
  //

  radio.printDetails();

}

void loop() {
  if ( radio.available() )
  {
    // Dump the payloads until we've gotten everything
    bool done = false;
    while (!done)
    {
      // Fetch the payload, and see if this was the last one.
      done = radio.read( &data, sizeof(word) );
      dataString = disassembleWord(data);
      Serial.println(dataString);
      // printf("Got payload %lu...",maze);

      // Delay just a little bit to let the other unit
      // make the transition to receiver
      delay(20);

    }

    // First, stop listening so we can talk
    radio.stopListening();

    Serial.println("sending back...");

    // Send the final one back.
    radio.write(&data, sizeof(word));


    // Now, resume listening so we catch the next packets.
    radio.startListening();

    if ( Serial.available() )
    {
      char c = toupper(Serial.read());
      role = role_pong_back;
      radio.openWritingPipe(pipes[1]);
      radio.openReadingPipe(1, pipes[0]);
    }
  }
  if (dataString.charAt(0) == '1'){
    digitalWrite(A5, HIGH);}
    if (dataString.charAt(1) == '0' && dataString.charAt(2) == '0') { //unexplored
      digitalWrite(A4, LOW);
      digitalWrite(7, LOW);
    }
    else if (dataString.charAt(1) == '0' && dataString.charAt(2) == '1') { //unexplored
      digitalWrite(A4, LOW);
      digitalWrite(7, HIGH); 
    }
    else if (dataString.charAt(1) == '1' && dataString.charAt(2) == '0') { //unexplored
      digitalWrite(A4, HIGH);
      digitalWrite(7, LOW);
    }
    else { //unexplored
      digitalWrite(A4, HIGH);
      digitalWrite(7, HIGH);
    }
    if (dataString.charAt(3) == '0' && dataString.charAt(4) == '0' && dataString.charAt(5) == '0') {
      digitalWrite(6, LOW);
      digitalWrite(5, LOW);
      digitalWrite(4, LOW);
    }
    else if (dataString.charAt(3) == '0' && dataString.charAt(4) == '0' && dataString.charAt(5) == '1') {
      digitalWrite(6, LOW);
      digitalWrite(5, LOW);
      digitalWrite(4, HIGH);
    }
    else if (dataString.charAt(3) == '0' && dataString.charAt(4) == '1' && dataString.charAt(5) == '0') {
      digitalWrite(6, LOW);
      digitalWrite(5, HIGH);
      digitalWrite(4, LOW);
    }
    else if (dataString.charAt(3) == '0' && dataString.charAt(4) == '1' && dataString.charAt(5) == '1') {
      digitalWrite(6, LOW);
      digitalWrite(5, HIGH);
      digitalWrite(4, HIGH);
    }
    else if (dataString.charAt(3) == '1' && dataString.charAt(4)=='0' && dataString.charAt(5) == '0') {
      digitalWrite(6, HIGH);
      digitalWrite(5, LOW);
      digitalWrite(4, LOW);
    }
    if (dataString.charAt(6) == '1'){
      digitalWrite(3,HIGH);
    } else {
      digitalWrite(3,LOW);
    }
      digitalWrite(2, LOW);
      delay(delayTime);
      digitalWrite(2, HIGH);
      delay(delayTime);


     digitalWrite(A5, LOW);
    if (dataString.charAt(9) == '1') { // top wall
      digitalWrite(A4, HIGH);
    } else {
      digitalWrite(A4, LOW);
    }

    if (dataString.charAt(10) == '1') { // left wall 
      digitalWrite(7, HIGH);
    } else {
      digitalWrite(7, LOW);
    }
    if (dataString.charAt(11) == '1') { // bottom wall
      digitalWrite(6, HIGH);
    } else {
      digitalWrite(6, LOW);
    }
    if (dataString.charAt(12) == '1') { // right wall
      digitalWrite(5, HIGH);
    } else {
      digitalWrite(5, LOW);
    }
    if (dataString.charAt(13) == '0' && dataString.charAt(14) == '1') {
      digitalWrite(4, LOW);
      digitalWrite(3, HIGH);
    }
    else if (dataString.charAt(13) == '1' && dataString.charAt(14) == '0') {
      digitalWrite(4, HIGH);
      digitalWrite(3, LOW);
    }
    else if (dataString.charAt(13) == '1' && dataString.charAt(14) == '1') {
      digitalWrite(4, HIGH);
      digitalWrite(3, HIGH);
    } else {
      digitalWrite(4, LOW);
      digitalWrite(3, LOW);
    }
  

//  if (coordinate) {
//    x ++;
//    if (x == 4) {
//      x = 0;
//      y++;
//    }
//    if (y == 5) {
//      y = 0;
//    }
//    printf(y);
//    coordinate = false;
//  }
//  else {
//    tres++;
//    if (tres == 0) {
//      tres = 1;
//    }
//    if (tres == 4) {
//      tres = 0;
//    }
//    coordinate = true;
//  }




  //printf(y);

  digitalWrite(2, LOW);
  delay(delayTime);
  digitalWrite(2, HIGH);
  delay(delayTime);


}

String disassembleWord(word data) {
  String stringToReturn;
  for (int i = 0; i < 16; i++) {
    int bitIndex = 15 - i;
    stringToReturn += String(bitRead(data, bitIndex));
  }
  return stringToReturn;
}

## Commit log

2017-10-30 arduino edits
2017-11-10 Left turn left wheel right turn right wheel
2017-11-19 added new Junction Sensor code
2017-11-30 since treasure won't be behind robot
    [DFSIntegration.ino]
2017-12-01 fixed the broken thing
    [DFS.ino]
2017-12-06 arduino pins

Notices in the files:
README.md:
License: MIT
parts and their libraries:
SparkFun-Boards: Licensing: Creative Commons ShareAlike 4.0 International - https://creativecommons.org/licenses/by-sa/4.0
